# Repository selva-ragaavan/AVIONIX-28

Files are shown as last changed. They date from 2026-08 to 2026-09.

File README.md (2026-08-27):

# AVIONIX-28
AVIONIX-28 Multi-Rail Power Supply Module for MIL-STD-704 Avionics Bus  A sequenced, EMI-filtered power conversion board that takes a 28V DC avionics bus input and produces regulated 5V, 3.3V, and 1.8V rails suitable for powering downstream digital/mixed-signal avionics electronics.

# AVIONIX-28
### Multi-Rail Power Supply Module for MIL-STD-704 Avionics Bus

A sequenced, EMI-filtered power conversion board that takes a 28V DC avionics
bus input and produces regulated 5V, 3.3V, and 1.8V rails suitable for
powering downstream digital/mixed-signal avionics electronics.

---

## 1. Overview

Every avionics subsystem — flight computers, sensor interface boards, radios,
display drivers — needs clean, sequenced, low-noise power derived from the
aircraft's primary 28V DC bus. This project implements that power stage as a
standalone module, designed against the electrical characteristics defined in
**MIL-STD-704** (Aircraft Electric Power Characteristics).

This is a learning/portfolio project intended to demonstrate practical power
electronics design skills relevant to defense and aerospace electronics work:
wide-input buck regulation, power sequencing, and EMI-aware layout.

## 2. Key Features

- **Input**: 28V DC nominal, designed to tolerate MIL-STD-704 transient
  conditions (18V–50V short-duration excursions, steady-state 22–29V)
- **Outputs**: 5V, 3.3V, 1.8V regulated rails
- **Sequencing**: Power-Good–gated startup order (5V → 3.3V → 1.8V)
- **Protection**: Reverse polarity protection, TVS transient clamping,
  overcurrent protection
- **EMI filtering**: Common-mode choke + differential filtering on the input
  stage, designed with MIL-STD-461 conducted emissions practices in mind

## 3. Design Reference: MIL-STD-704

| Parameter | Spec |
|---|---|
| Nominal bus voltage | 28V DC |
| Normal steady-state range | ~22V – 29V DC |
| Undervoltage transient | down to ~18V (short duration) |
| Overvoltage transient | up to ~50V (short duration) |
| Ripple | up to 1.5V p-p |

## 4. Power Rail Application Map

| Rail | Voltage | Typical Consumers | Logic Family | Function on Board |
|---|---|---|---|---|
| Rail 1 | 5.0V | RS-422/RS-485 transceiver, op-amp/comparator, ADC analog supply | TTL / 5V CMOS | Legacy interface signaling to other avionics units, analog sensor conditioning |
| Rail 2 | 3.3V | MCU (I/O + peripherals), MIL-STD-1553/ARINC429 transceiver, Flash/EEPROM | LVCMOS / LVTTL | Main digital logic, bus communication, non-volatile storage |
| Rail 3 | 1.8V | Precision ADC reference / analog front-end (or reserved for expansion) | LVCMOS 1.8V | Low-noise reference rail for precision analog, or provisioned future use |

The input protection stage is designed to survive these conditions without
damage or latch-up, and to maintain regulation through normal operating
excursions.

## 5. Architecture

     28V BUS
                │
                ▼
       ┌─────────────────┐
       │  5V BUCK STAGE   │   28V → 5V
       └─────────────────┘
          │           │
          │ 5V rail   │ PG
          ▼           ▼
       ┌─────────────────┐
       │   3.3V STAGE     │   5V → 3.3V
       └─────────────────┘
          │           │
          │ 3.3V rail │ PG
          ▼           ▼
       ┌─────────────────┐
       │   1.8V STAGE     │   3.3V → 1.8V
       └─────────────────┘
          │           │
          │ 1.8V rail │ PG
          ▼           ▼

- Sequencing stage-to-stage via the power-good pin, rather than a fixed timer, ensures each rail only comes up once the previous one has settled — giving stable, deterministic power-up behavior.
- The staged, gated startup also helps avoid switching-noise-induced false triggering on downstream LVCMOS-family logic, following practices described in Analog Devices' multi-rail power supply design guidance (Analog Dialogue, Part 1).

## 6. Reference articles and resources used in this  design:
- Analog.com Multirail_Powersupply Design part1: https://www.analog.com/en/resources/analog-dialogue/articles/multirail-power-supply-design-for-successful-application-boards-part1.html  ,
- part2: https://www.analog.com/en/resources/analog-dialogue/articles/multirail-power-supply-design-for-successful-application-boards-part2.html
- Esd Protection: https://youtu.be/MmG_m4xVNfQ?si=btMzvDi-hvi9JBXi
- buck ic calculations : https://www.ti.com/lit/an/slva477b/slva477b.pdf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
## 7. Disclaimer

This is an educational/portfolio project. It follows MIL-STD-704 and
MIL-STD-461 design *principles* for learning purposes but has not undergone
formal qualification or certification testing, and is not intended for use
in actual flight hardware.

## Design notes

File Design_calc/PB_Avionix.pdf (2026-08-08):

Comp | Voltage(v) Current(I) power(w) duty cycle contigency total power
ADC/RS422 5V | 95mA | 0.5w | 100 | 50% 0.75w
Flash/Mcu 3.3V | 350mA | 1.15w | 100 | 50% 1.725w
24B ADC | 1.8V | 15mA | 0.1w | 100 | 50% 0.15w
Total: | 2.025

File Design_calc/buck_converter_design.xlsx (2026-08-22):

Buck Converter Design Calculations
Input Parameters
Vin (V) | 28
Vout (V) | 5
Efficiency/derating factor | 0.85 | worst case
L selected - datasheet min (uH) | 15uH
L actual used (uH) | 24
Switching Frequency Fsw (kHz) | 500
HS current limit, datasheet (A) | 3.9
LS current limit, datasheet (A) | 4
Max load current Iout (A) | 0.5
R4 (kohm) | 100
R5 (kohm) | 13.3
Duty Cycle
Dmax = (Vout/Vin) * factor | 0.151D
Inductor Ripple Current (using min L)
Delta I = (Vin-Vout)*D / (Fsw*L) | 0.4800 | with the datasheet min inductance
Delta I with L actual used
Current Limit Margins
HS current limit w/ margin (A) | 4-0.24> Iout(max)
LS current limit w/ margin (A) | 4-0.24>Iout(max)
Max switching current (Iout + margin) |  | 0.74A
HS margin vs max switching current (A)
LS margin vs max switching current (A)
Feedback Resistor Divider : calculated from the datasheet
R4 = 100k, R5 = 13.3k
Input Capacitors

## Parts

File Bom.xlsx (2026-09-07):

Item # | *Designator | *Qty | Manufacturer | *Mfg Part # | Description / Value | *Package/Footprint | Type | Your Instructions / Notes
1 | J1,J2,J3,J4 | 4 | Degson | 15EDGVC-3 | 28v,5v,3.3v,1.8v rail input and output |  | thru-hole
2 | C1 | 2 | murata | GRM32ER71J106KA12L | 10uF input decoupling | 1210 | smd
3 | C2 | 1 | murata | GRM155R71H104KE14J | 0.1uF for high frequency | O4O2 | smd
4 | C3 | 1 | murata | GRM155R71H104KE14J | 0.1uF | O4O2 | smd
5 | C4,C5 | 1 each | murata | GRM32ER71E226ME15L | 22uF each | 1210 | smd
6 | C6 | 1 | murata | TCC0805COG750J500BT | 75pF | 0805
7 | R2 | 1 | any | Nil | 100k | 0805 | smd
8 | R3 | 1 | any | Nil | 13k3 | 0805 | smd
9 | L1 | 1 | Vishay | CD54NP-220MC | 22uH |  | smd
10 | R1 | 1 | any | Nil | 51 | 0805 | smd
11 | U1 | 1 | Texas | TPS54202DDCT | Ic for taping down 28v input to 5v | SOT -6 | smd

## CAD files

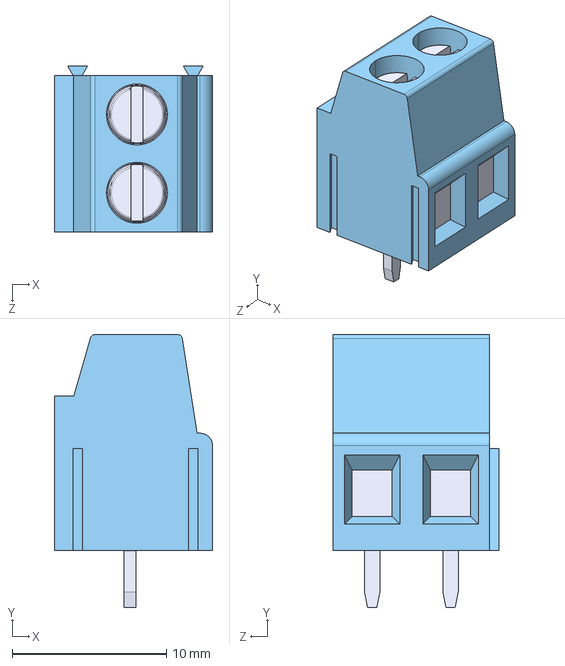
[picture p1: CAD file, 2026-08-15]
Avionix-28_Pcbfiles/_restore_backup_2026-08-23T18-25-53-473/Models/FOOTPRINTS/TB007-508-02BE/TB007-508-02BE.step
10.2 x 17.7 x 10.8 mm

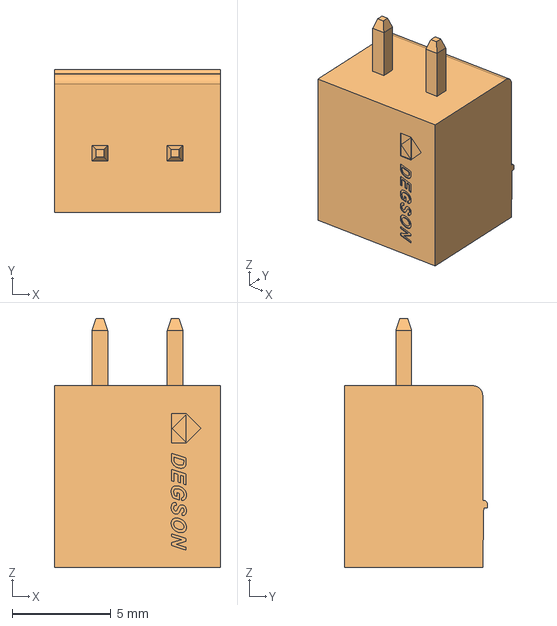
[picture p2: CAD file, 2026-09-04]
Avionix-28_Pcbfiles/_restore_backup_2026-08-23T18-25-53-473/Models/FOOTPRINTS/Screw_terminal/15EDGVC-3.81-02P-14-00A&Z(H).stp
8.41 x 7.24 x 12.6 mm

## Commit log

2026-08-08 added power budget
2026-08-14 added block terminal
    [Avionix-28_Pcbfiles.kicad_pcb, Avionix-28_Pcbfiles.kicad_sch]
2026-08-15 added models and footprints
    [TB007-508-02BE.step]
2026-08-17 ic for buck operation + datasheet inclusion
    [Avionix-28_Pcbfiles.kicad_sch]
2026-08-19 added calc regararding buck
    [buck_converter_design.xlsx]
2026-08-19 added symbols and fprint for buck
    [Avionix-28_Pcbfiles.kicad_sch, buck_converter_design.xlsx]
2026-08-20 updated input caps
    [buck_converter_design.xlsx]
2026-08-20 worked up on sch
    [Avionix-28_Pcbfiles.kicad_sch]
2026-08-22 added new ic
    [buck_converter_design.xlsx]
2026-08-24 base bom
    [Avionix-28_Pcbfiles.kicad_pcb, Avionix-28_Pcbfiles.kicad_sch, Bom.xlsx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]
2026-08-24 updated bom
    [Bom.xlsx]
2026-08-31 added filtering caps
    [Bom.xlsx]
2026-09-04 completed bom
2026-09-04 corrected Bom
    [Bom.xlsx]
2026-09-04 changes added
    [Bom.xlsx]
2026-09-04 changed inductor value and assigned footprints
    [15EDGVC-3.81-02P-14-00A&Z(H).stp, Avionix-28_Pcbfiles.kicad_sch]
2026-09-04 done v1 schematics
    [Bom.xlsx]
